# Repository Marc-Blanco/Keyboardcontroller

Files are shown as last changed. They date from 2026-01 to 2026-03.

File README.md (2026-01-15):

# Keyboardcontroller 
It´s a keyboard with the objective of being a leverless controller inspired by the arcade controllers specially designed for playing fgc games. All controlled with a raspberrypi PICO. It's main prupose its to serve as a controller for Street fighter, Tekken, etc... But it's sure that I will find more uses to it. It's Inspired by [Hitbox controllers](https://www.hitboxarcade.com/) and I do plan on making a levered version of it, it could be interpreted as a Keyboard extension also.

## PCB
Schematic


PCB


## CAD
All fitted togheter



## Assembly

# Firmware
I found already done Firmware for raspberrypi picos https://github.com/OpenStickCommunity/GP2040-CE?tab=readme-ov-file

## BOM
| Part | Quantity | Price  | Link | Notes |
| --- | --- | --- | --- | --- |
| PCB | 5 | $25.86 + 25$ for customs | [JLCPCB](https://jlcpcb.com/) | Yes, the shipment charges cost 25$. All this include the PCB the top case the bottom part and the buttons | |
| Kailh Low Profile Choc Switches | 14 | €26.35 | [splitkb](https://splitkb.com/products/kailh-low-profile-choc-switches) | Dutch company avoiding potential customs |
| Raspberrypi Pico | 1 | $0.99  | [Aliexpress](https://es.aliexpress.com/item/1005003371056277.html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) | Aliexpress Quality 
 | Total cost | | 80,57,7 |                                                                                                                                                                                                                                                 

---

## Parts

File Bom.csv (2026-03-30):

Part | Quantity | Price | Link | Notes
PCB | 5 | 25.86 + 25 for customs | https://jlcpcb.com/ | Yes, the shipment charges cost 25$. All this include the PCB the top case the bottom part and the buttons
Kailh Low Profile Choc Switches | 14 | €26.35 | https://splitkb.com/products/kailh-low-profile-choc-switches | Dutch company avoiding potential customs
Raspberrypi Pico | 1 | $0.99 | https://es.aliexpress.com/item/1005003371056277.html?utparam-url=scene%3Asearch%7Cquery_from%3A | Aliexpress Quality
Total cost |  | 80,57,7

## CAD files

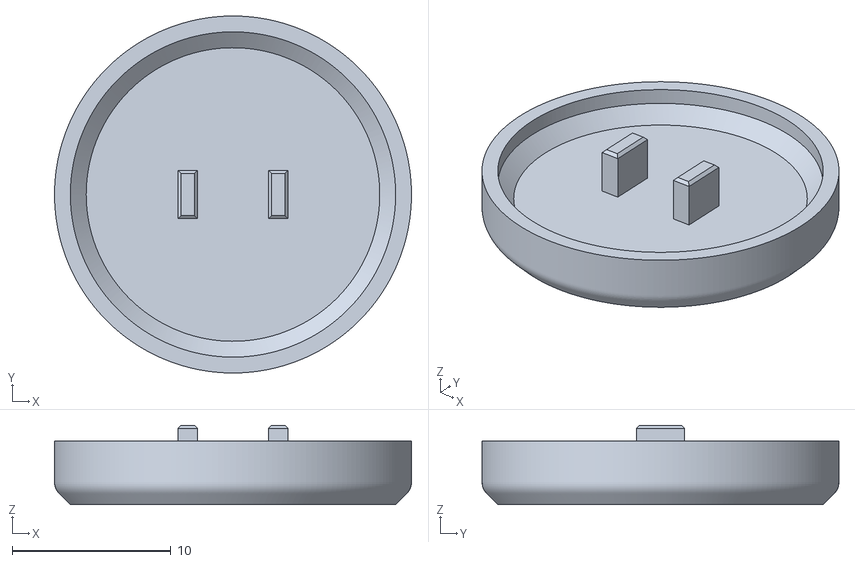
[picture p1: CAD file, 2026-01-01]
models/CAD/Buttoncapçal.stl
22.5 x 22.5 x 5.00

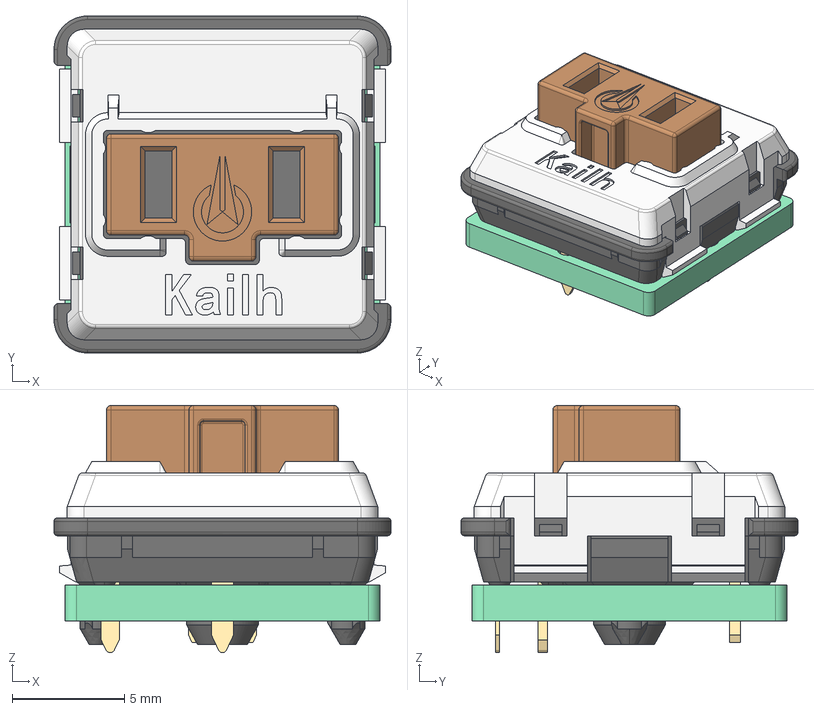
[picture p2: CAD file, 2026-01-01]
models/CAD/Kailh Choc Low Profile Switch.step
15.0 x 15.0 x 11.0 mm

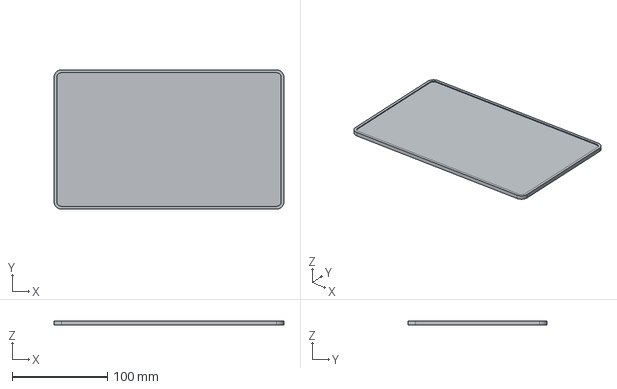
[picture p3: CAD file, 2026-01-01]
models/CAD/back-Body.step
241.0 x 146.0 x 4.40 mm

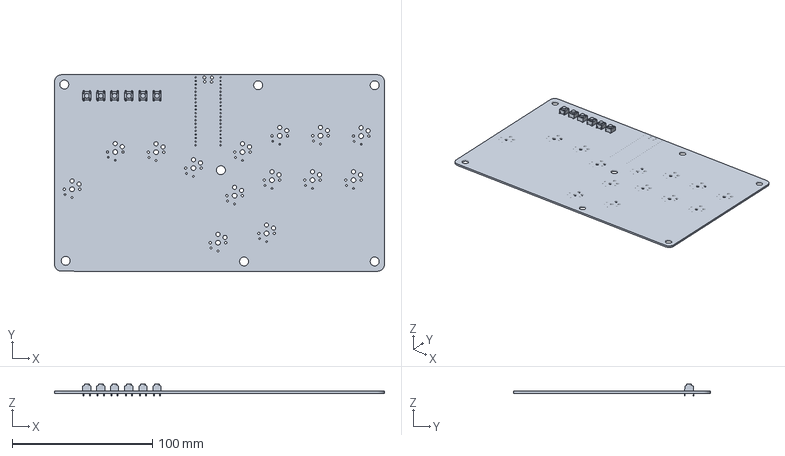
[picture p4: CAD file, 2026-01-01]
models/CAD/Sin nombre1.FCStd
235.0 x 140.0 x 8.50 mm

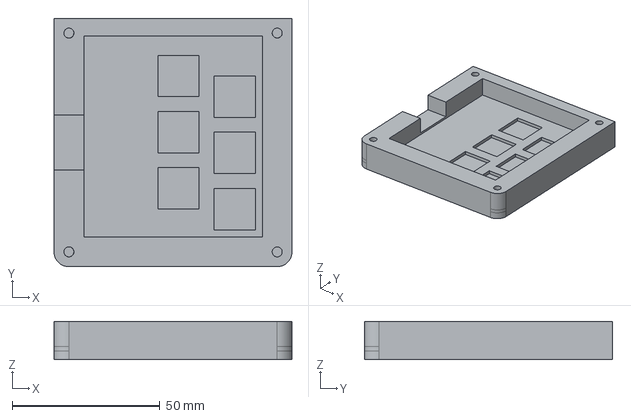
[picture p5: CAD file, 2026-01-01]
models/CAD/Front.step
80.5 x 84.0 x 13.0 mm

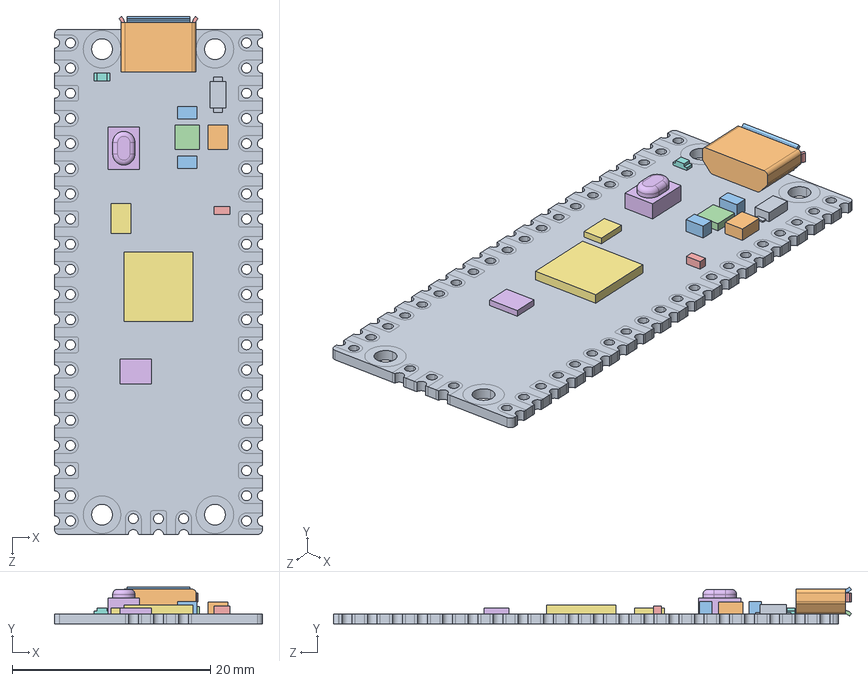
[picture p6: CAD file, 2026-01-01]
models/CAD/Pico-R3.step
21.0 x 3.73 x 52.3 mm
PICO_REF_BOARD.STEP
PICO_REF_USB.STEP
PICO_REF_SWITCH.STEP
PICO_REF_MICROCONTROLLER.STEP
PICO_REF_LED.STEP
PICO_REF_ONSEMI.STEP
PICO_BOURNS.STEP
PICO_MURATA.STEP x 2
PICO_RICHTEK.STEP
PICO_DIODES.STEP
PICO_AEL.STEP
PICO_WINBOND.STEP

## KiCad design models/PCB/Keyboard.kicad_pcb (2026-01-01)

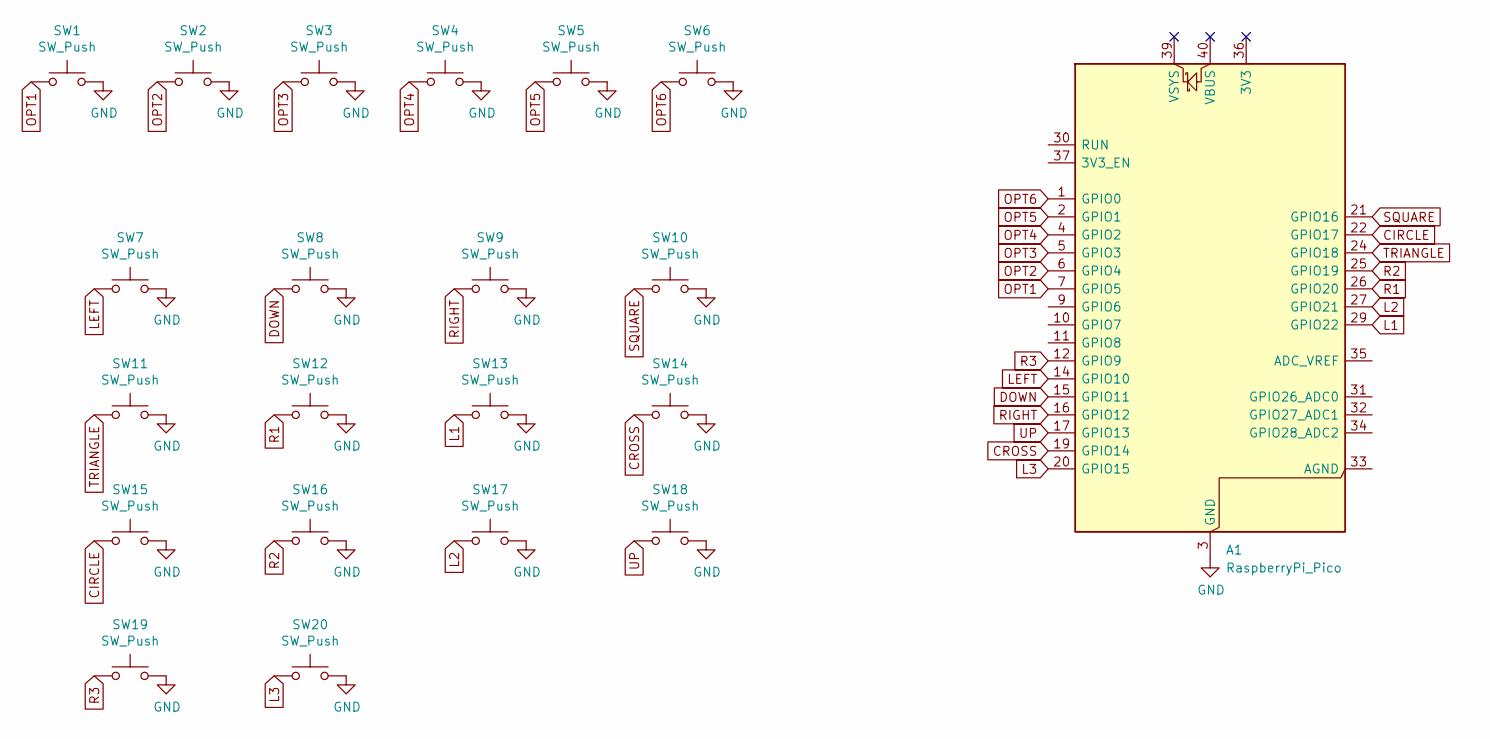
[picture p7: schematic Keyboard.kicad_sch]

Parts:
A1: RaspberryPi_Pico; RaspberryPi_Pico_Common_Unspecified
SW1, SW2, SW3, SW4, SW5, SW6: SW_Push; SW_PUSH_6mm_H5mm
SW7, SW8, SW9, SW10, SW11, SW12, SW13, SW14, SW15, SW16, SW17, SW18, SW19, SW20: SW_Push; Kailh_socket_PG1350_optional

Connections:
CIRCLE: A1.22 (GPIO17), SW15.1
CROSS: A1.19 (GPIO14), SW14.1
DOWN: A1.15 (GPIO11), SW8.1
GND: A1.3 (GND), A1.8 (GND), A1.13 (GND), A1.18 (GND), A1.23 (GND), A1.28 (GND), A1.38 (GND), SW1.2, SW2.2, SW3.2, SW4.2, SW5.2, SW6.2, SW7.2, SW8.2, SW9.2, SW10.2, SW11.2, SW12.2, SW13.2, SW14.2, SW15.2, SW16.2, SW17.2, SW18.2, SW19.2, SW20.2
L1: A1.29 (GPIO22), SW13.1
L2: A1.27 (GPIO21), SW17.1
L3: A1.20 (GPIO15), SW20.1
LEFT: A1.14 (GPIO10), SW7.1
OPT1: A1.7 (GPIO5), SW1.1
OPT2: A1.6 (GPIO4), SW2.1
OPT3: A1.5 (GPIO3), SW3.1
OPT4: A1.4 (GPIO2), SW4.1
OPT5: A1.2 (GPIO1), SW5.1
OPT6: A1.1 (GPIO0), SW6.1
R1: A1.26 (GPIO20), SW12.1
R2: A1.25 (GPIO19), SW16.1
R3: A1.12 (GPIO9), SW19.1
RIGHT: A1.16 (GPIO12), SW9.1
SQUARE: A1.21 (GPIO16), SW10.1
TRIANGLE: A1.24 (GPIO18), SW11.1
UP: A1.17 (GPIO13), SW18.1

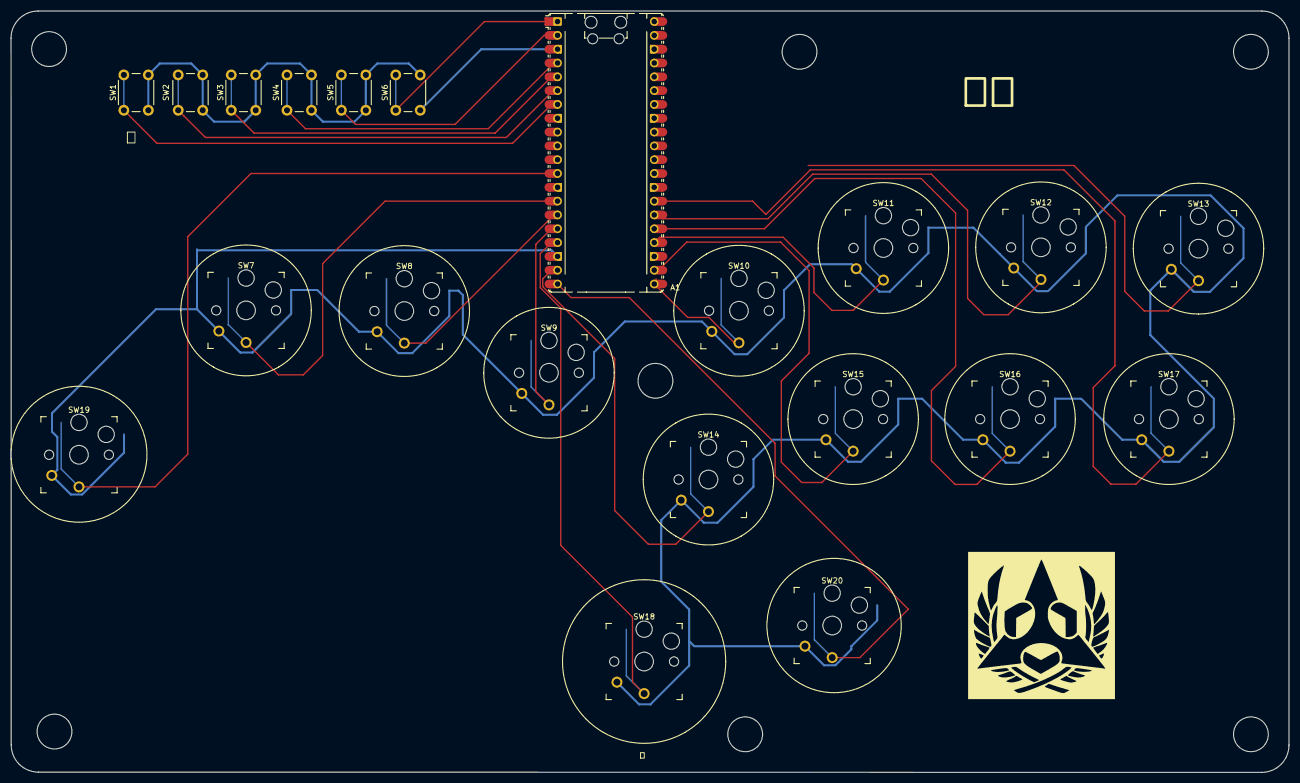
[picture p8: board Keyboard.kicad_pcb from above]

Board: 2 copper layers, 235.0 x 140.0 mm, 21 parts (0 on the bottom side), 21 nets.

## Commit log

2026-01-01 Create PCB
2026-01-01 Add new PCBa model
